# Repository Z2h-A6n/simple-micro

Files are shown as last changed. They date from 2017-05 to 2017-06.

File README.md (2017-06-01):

# Simple Micro
KiCad files for a simple microcontroller breakout board. Nearly a clone of the
[Sparkfun Pro Micro](https://www.sparkfun.com/products/12640)

## Overview
This is a simple breakout board for the Atmel ATMega32u4 microcontroller that is
very closely based on the Pro Micro by Sparkfun Electonics. The primary
differences between the Pro Micro and the Simple Micro are:
- The Pro Micro is physically smaller.
- The Simple Micro breaks out a few more of the I/O pins on the ATMega.
- The USB pins on the Simple Micro are broken out to through-hole pads as well as a surface-mount USB receptacle.
- The Simple Micro is cheaper (as of this writing).
  - e.g. Making 3 Simple Micros with boards from OSH Park and components from DigiKey cost $34. See the [example parts list](parts-list.txt).
- The Pro Micro comes pre-built.
- The Pro Micro was made by people who presumably know what they are doing, while the Simple Micro was designed by someone with no formal training in microcontroller use or PCB design.

## Files in this repo
Most of the files in the repo are KiCad project files. The other files are:
- assembly.pdf
  - A pdf showing the exposed pads on the bare PCB marked up with component labels to help with assembling the board.
- README.md
  - This document.

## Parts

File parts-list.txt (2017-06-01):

The following is an example parts lists using parts from digikey.com.

Quantity  Part Number          Manufacturer Part Number  Description                      Unit Price  Extended Price
--------  ----------           ------------------------  -----------                      ----------  --------------
10        1276-2229-1-ND       CL10C220JB8NNWC           CAP CER 22PF 50V C0G/NP0 0603    0.02400     $0.24
10        1276-1182-1-ND       CL10A105KP8NNNC           CAP CER 1UF 10V X5R 0603         0.02800     $0.28
25        1276-1005-1-ND       CL10B104KO8NNNC           CAP CER 0.1UF 16V X7R 0603       0.01200     $0.30
10        311-22GRCT-ND        RC0603JR-0722RL           RES SMD 22 OHM 5% 1/10W 0603     0.01000     $0.10
10        311-10KGRCT-ND       RC0603JR-0710KL           RES SMD 10K OHM 5% 1/10W 0603    0.01000     $0.10
3         ATMEGA32U4-AURCT-ND  ATMEGA32U4-AUR            IC MCU 8BIT 32KB FLASH 44TQFP    4.20000     $12.60
3         478-8192-1-ND        F931A106KAA CAP           TANT 10UF 10V 10% 1206           0.31000     $0.93
4         535-13466-1-ND       ABM8-16.000MHZ-7-1-U-T    CRYSTAL 16.0000MHZ 7PF SMD       0.48000     $1.92
3         507-1802-1-ND        0ZCJ0050FF2G              PTC RESTTBLE 0.50A 8V CHIP 1206  0.13000     $0.39

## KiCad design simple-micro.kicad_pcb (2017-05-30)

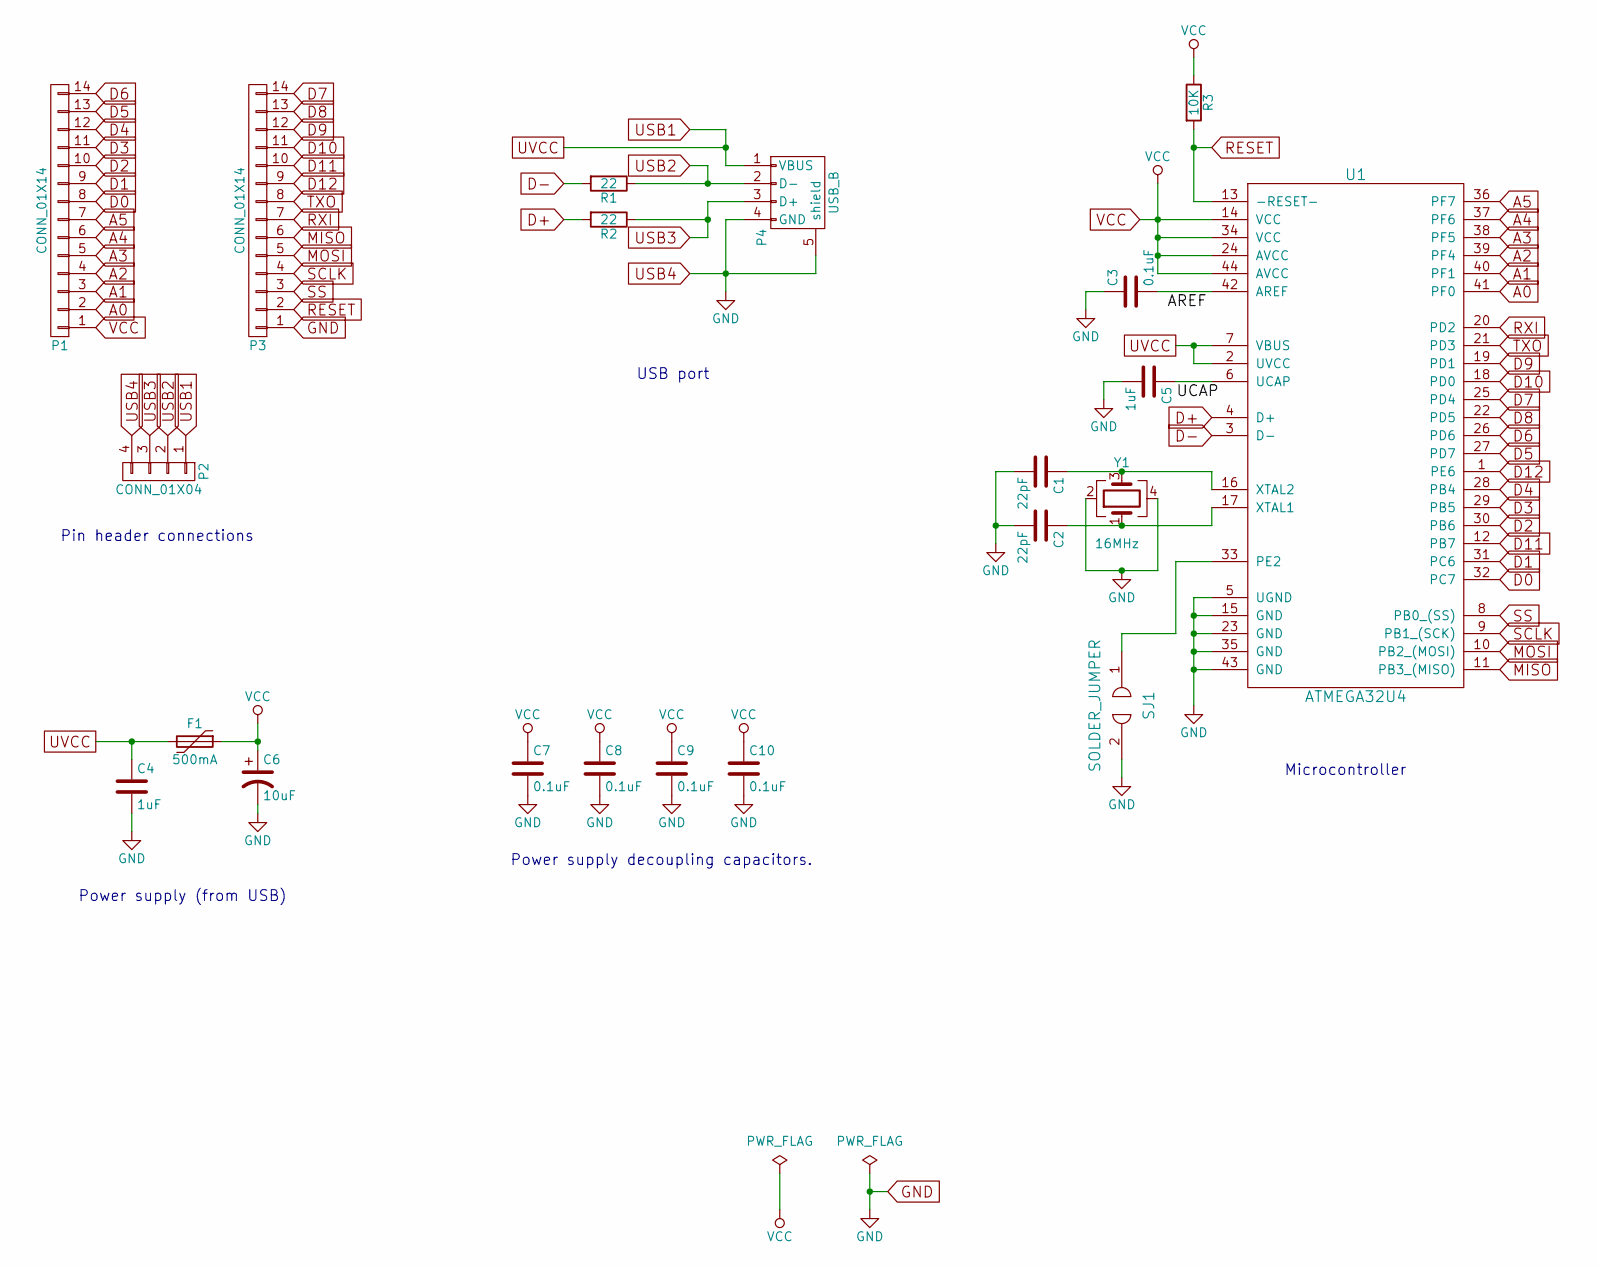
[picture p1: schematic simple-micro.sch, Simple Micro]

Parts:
C1, C2: 22pF; C_0603
C3, C7, C8, C9, C10: 0.1uF; C_0603
C4, C5: 1uF; C_0603
C6: 10uF; Tantalum_Case-A_EIA-3216-18_Reflow
F1: 500mA; Fuse_SMD1206_Reflow
P1, P3: CONN_01X14; Pin_Header_Straight_1x14
P2: CONN_01X04; Pin_Header_Straight_1x04
P4: USB_B; USB_MICROB_SMD-TH
R1, R2: 22; R_0603
R3: 10K; R_0603
SJ1: SOLDER_JUMPER; Solder_Jumper
U1: ATMEGA32U4; TQFP-44_10x10mm_Pitch0.8mm
Y1: 16MHz; Crystal_SMD_3.2X2.5_4PAD

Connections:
A0: P1.2, U1.41 (PF0)
A1: P1.3, U1.40 (PF1)
A2: P1.4, U1.39 (PF4)
A3: P1.5, U1.38 (PF5)
A4: P1.6, U1.37 (PF6)
A5: P1.7, U1.36 (PF7)
D0: P1.8, U1.32 (PC7)
D1: P1.9, U1.31 (PC6)
D2: P1.10, U1.30 (PB6)
D3: P1.11, U1.29 (PB5)
D4: P1.12, U1.28 (PB4)
D5: P1.13, U1.27 (PD7)
D6: P1.14, U1.26 (PD6)
D7: P3.14, U1.25 (PD4)
D8: P3.13, U1.22 (PD5)
D9: P3.12, U1.19 (PD1)
D10: P3.11, U1.18 (PD0)
D11: P3.10, U1.12 (PB7)
D12: P3.9, U1.1 (PE6)
D+: R2.2, U1.4 (D+)
D-: R1.2, U1.3 (D-)
GND: C1.2, C2.2, C3.1, C4.2, C5.2, C6.2, C7.2, C8.2, C9.2, C10.2, P2.4, P3.1, P4.4 (GND), P4.5 (shield), SJ1.2, U1.5 (UGND), U1.15 (GND), U1.23 (GND), U1.35 (GND), U1.43 (GND), Y1.2, Y1.4
MISO: P3.6, U1.11 (PB3_(MISO))
MOSI: P3.5, U1.10 (PB2_(MOSI))
unnamed: C1.1, U1.16 (XTAL2), Y1.3
unnamed: C2.1, U1.17 (XTAL1), Y1.1
unnamed: C3.2, U1.42 (AREF)
unnamed: C5.1, U1.6 (UCAP)
unnamed: SJ1.1, U1.33 (PE2)
RESET: P3.2, R3.2, U1.13 (-RESET-)
RXI: P3.7, U1.20 (PD2)
SCLK: P3.4, U1.9 (PB1_(SCK))
SS: P3.3, U1.8 (PB0_(SS))
TXO: P3.8, U1.21 (PD3)
USB1: C4.1, F1.2, P2.1, P4.1 (VBUS), U1.2 (UVCC), U1.7 (VBUS)
USB2: P2.2, P4.2 (D-), R1.1
USB3: P2.3, P4.3 (D+), R2.1
VCC: C6.1, C7.1, C8.1, C9.1, C10.1, F1.1, P1.1, R3.1, U1.14 (VCC), U1.24 (AVCC), U1.34 (VCC), U1.44 (AVCC)

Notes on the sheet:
Power supply decoupling capacitors.
Power supply (from USB)
Pin header connections
USB port
Microcontroller

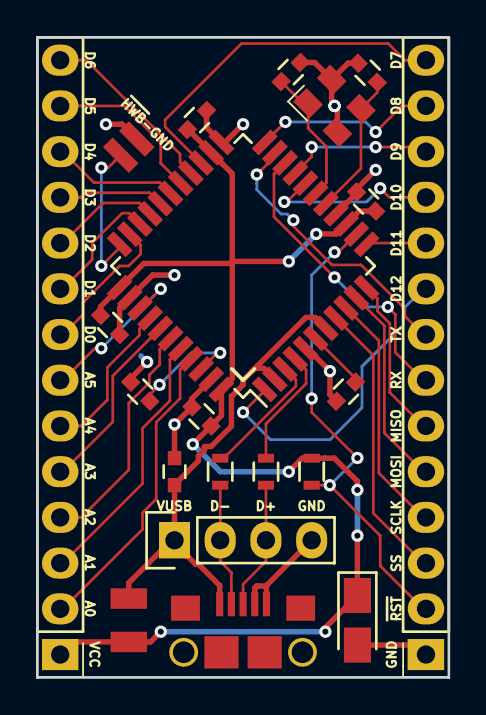
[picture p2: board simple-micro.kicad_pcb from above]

Board: 2 copper layers, 22.9 x 35.6 mm, 21 parts (0 on the bottom side), 38 nets.

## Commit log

2017-05-30 Initial commit. v1.0
    This is the first version sent to the fab.
    [simple-micro.kicad_pcb, simple-micro.sch]
2017-06-01 added assembly notes

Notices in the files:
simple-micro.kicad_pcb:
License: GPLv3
